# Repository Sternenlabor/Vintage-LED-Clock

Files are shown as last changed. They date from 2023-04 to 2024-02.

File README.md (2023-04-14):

# Vintage-LED-Clock
# WiFi configuration
SSID and credentials are kept in a separate file which is not included in GIT repository.   
Create file *credentials.h* in *src* folder and add SSID and WiFi password.   
e.g.:

    #ifndef _CREDENTIALS_H_
    #define _CREDENTIALS_H_

    const char cstrSSID[] = "MyNetwork";
    const char cstrPWD[] = "secret";

    #endif /* _CREDENTIALS_H_ */

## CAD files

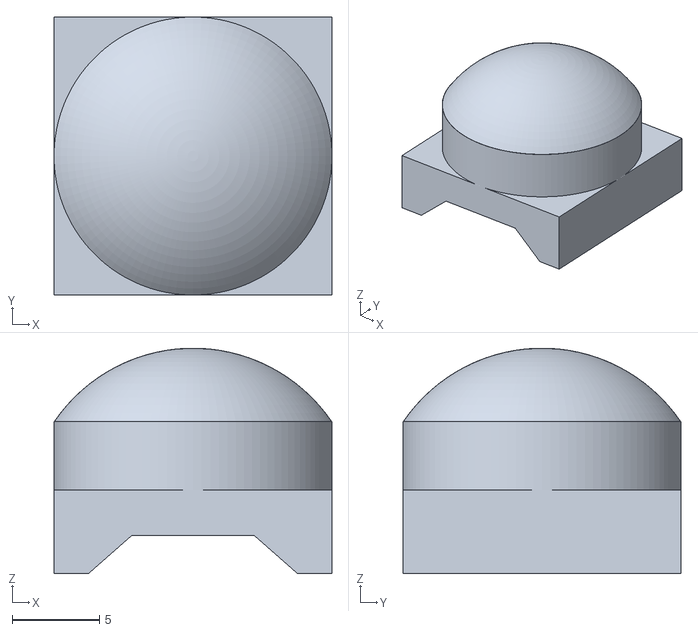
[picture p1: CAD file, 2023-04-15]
hardware/led-case/led-case.stl
15.9 x 15.9 x 12.9

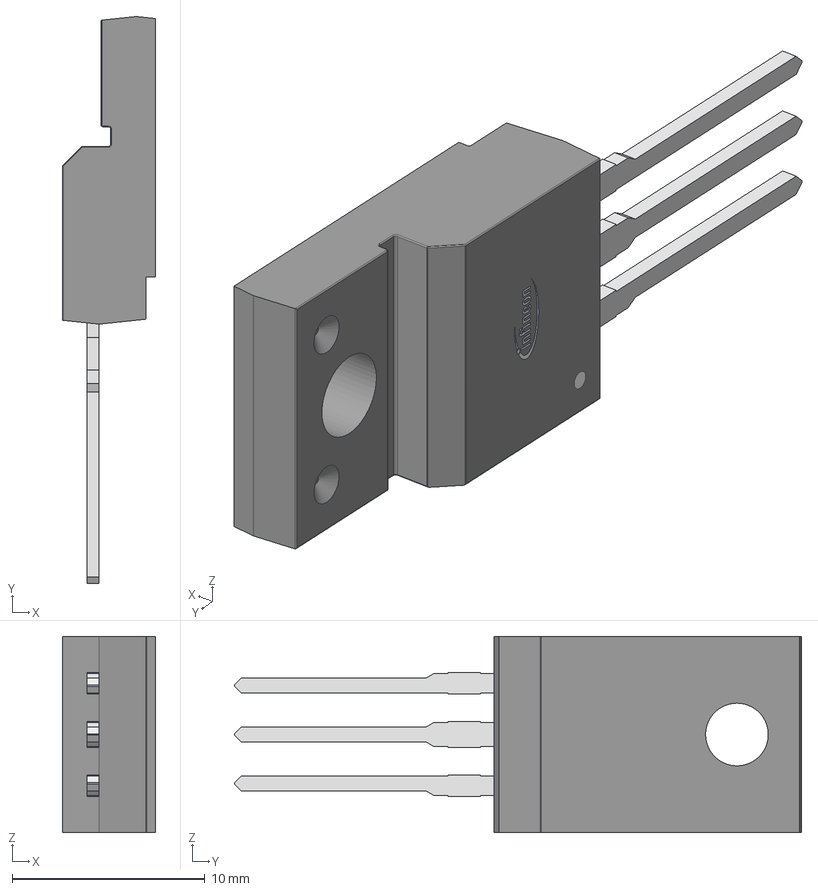
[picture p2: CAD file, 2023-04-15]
hardware/led-clock-mainboard/parts/IRF1404PBF.models/Infineon_Technologies_-_IRF1404PBF.step
4.83 x 29.4 x 10.2 mm
Infineon IRFB4127PbF 1
Infineon IRFB4127PbF 2
Infineon IRFB4127PbF 2_1
Infineon IRFB4127PbF 2 - Copy_MIR1
Infineon

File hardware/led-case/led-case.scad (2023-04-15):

$fn = 100;

width = 15.9; //mm
base_height = 4.8; //mm
ring_height = 3.9; //mm
overall_height = 12.9; //mm
wall_thickness = 0.9; //mm

cutout_height = 2.2; //mm
cutout_top_width = 5; //mm
cutout_bottom_width = 12; //mm

color("red") {
    difference() {
        
        // outer
        union() {
            translate([0, 0, base_height / 2]) cube([width, width, base_height], center=true);
            cylinder(base_height + ring_height, width / 2, width / 2);
            radius = (width / 2) + 1.65;
            difference() {
                translate([0, 0, overall_height - radius]) sphere(radius);
                translate([0, 0, -25 + base_height + ring_height]) cube([50, 50, 50], center=true); // mask
            }
        }
        
        // inner
        union() {
            w = wall_thickness;
            translate([0, 0, base_height / 2 - w - 0.01]) cube([width - 2 * w, width - 2 * w, base_height - 2 * w], center=true);
            cylinder((base_height + ring_height), (width - 2 * w) / 2, (width - 2 * w) / 2);
            
            radius = (width / 2) + 1;
            difference() {
                translate([0, 0, overall_height - radius - w + 0.05]) sphere(radius);
                translate([0, 0, -100 + base_height + ring_height - w + 0.8]) cube([200, 200, 200], center=true); // mask
            }
            
        }
        
        // cutout
        translate([-cutout_bottom_width / 2, width, -0.01]) rotate([90, 00, 0]) color("blue") linear_extrude(2 * width) polygon(points=[[0, 0], [cutout_bottom_width, 0],[cutout_bottom_width - cutout_top_width / 2, cutout_height], [cutout_top_width / 2, cutout_height]]);
        
        // Test
        //translate([0, 25, 0]) cube([50, 50, 50], center=true); // mask   
    }
}

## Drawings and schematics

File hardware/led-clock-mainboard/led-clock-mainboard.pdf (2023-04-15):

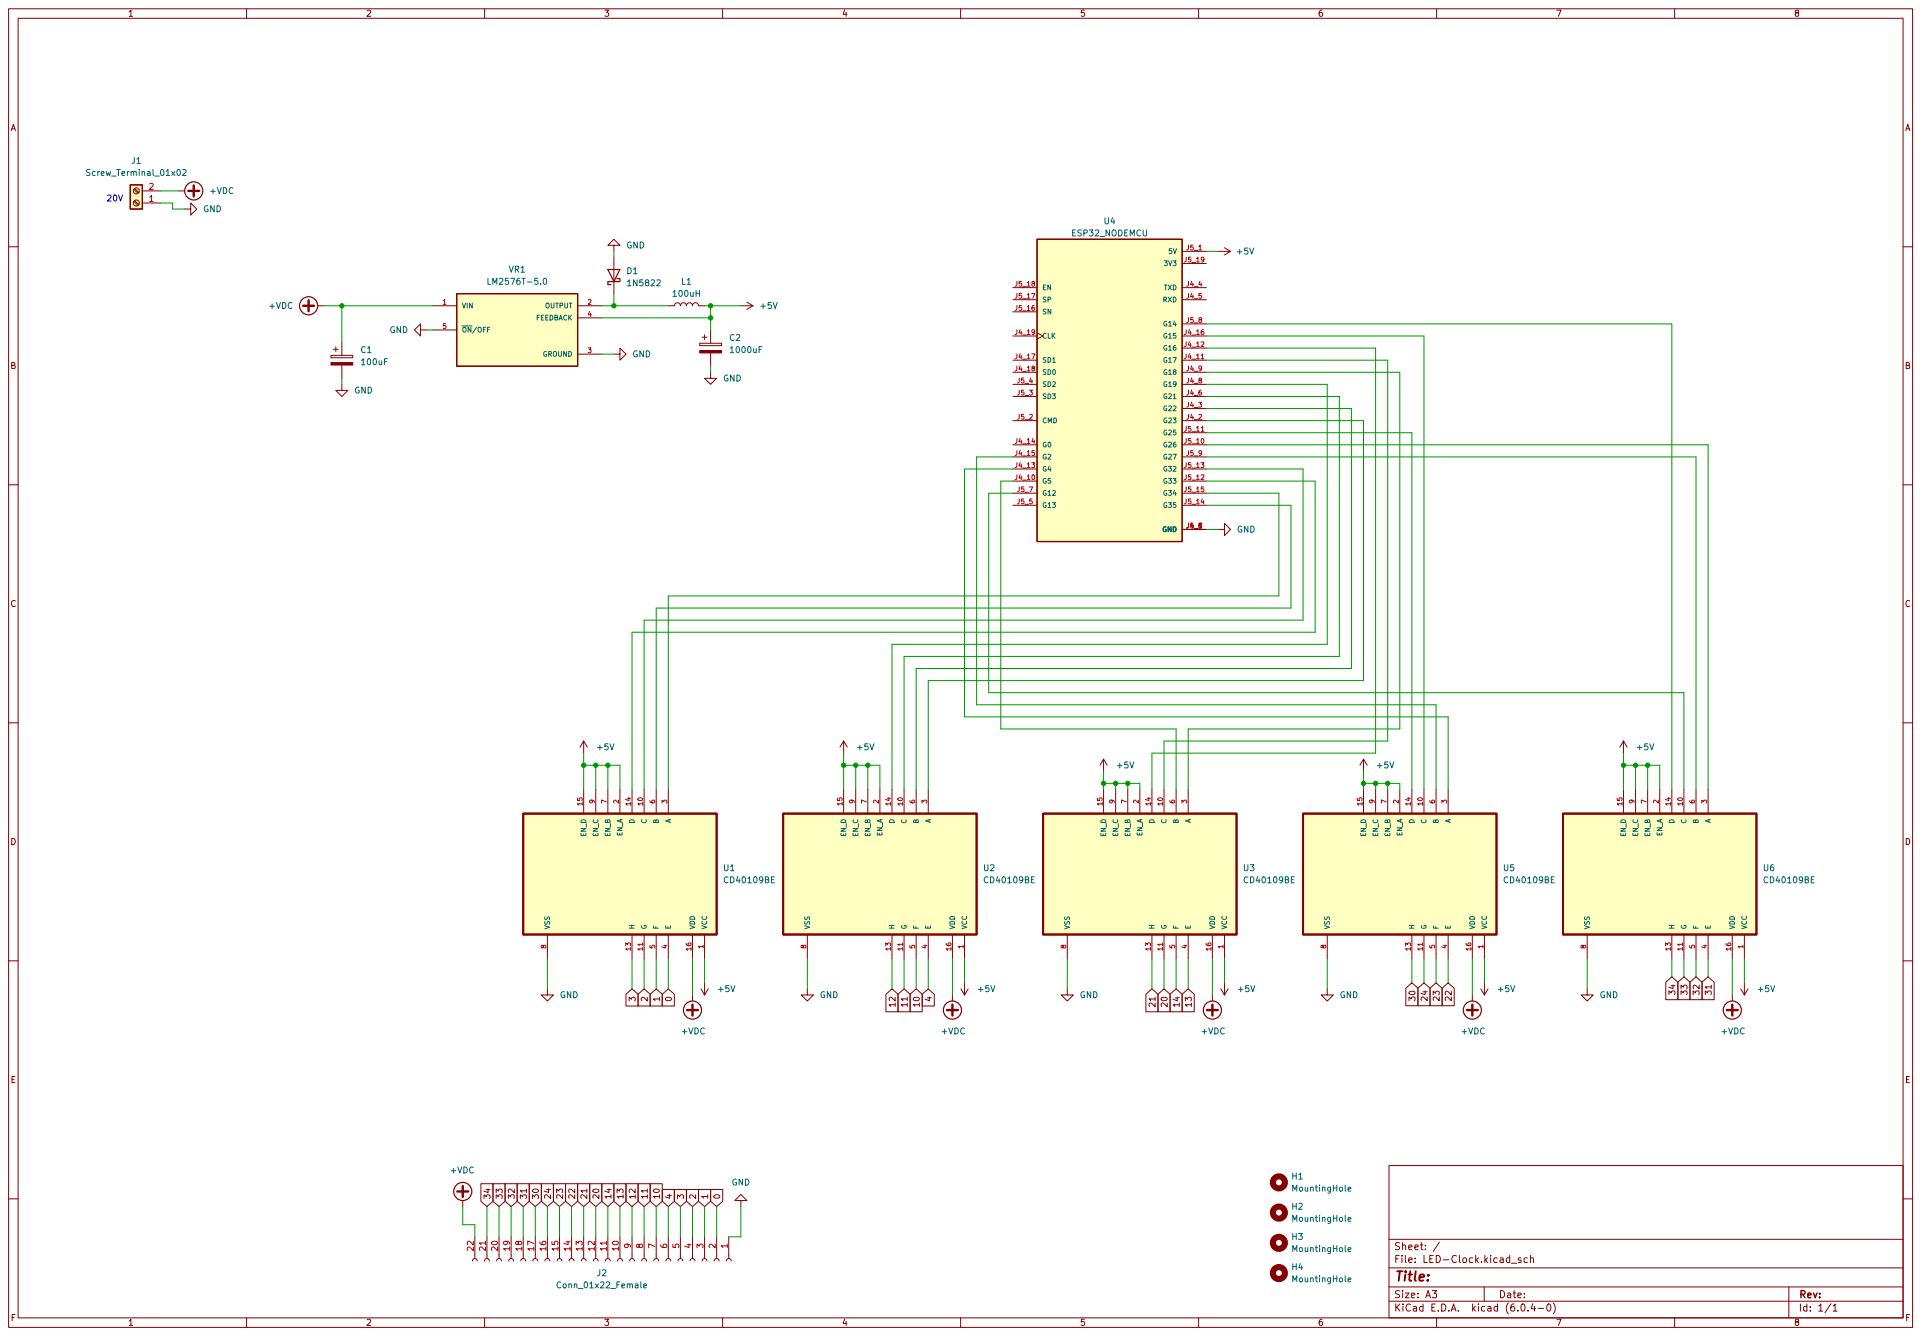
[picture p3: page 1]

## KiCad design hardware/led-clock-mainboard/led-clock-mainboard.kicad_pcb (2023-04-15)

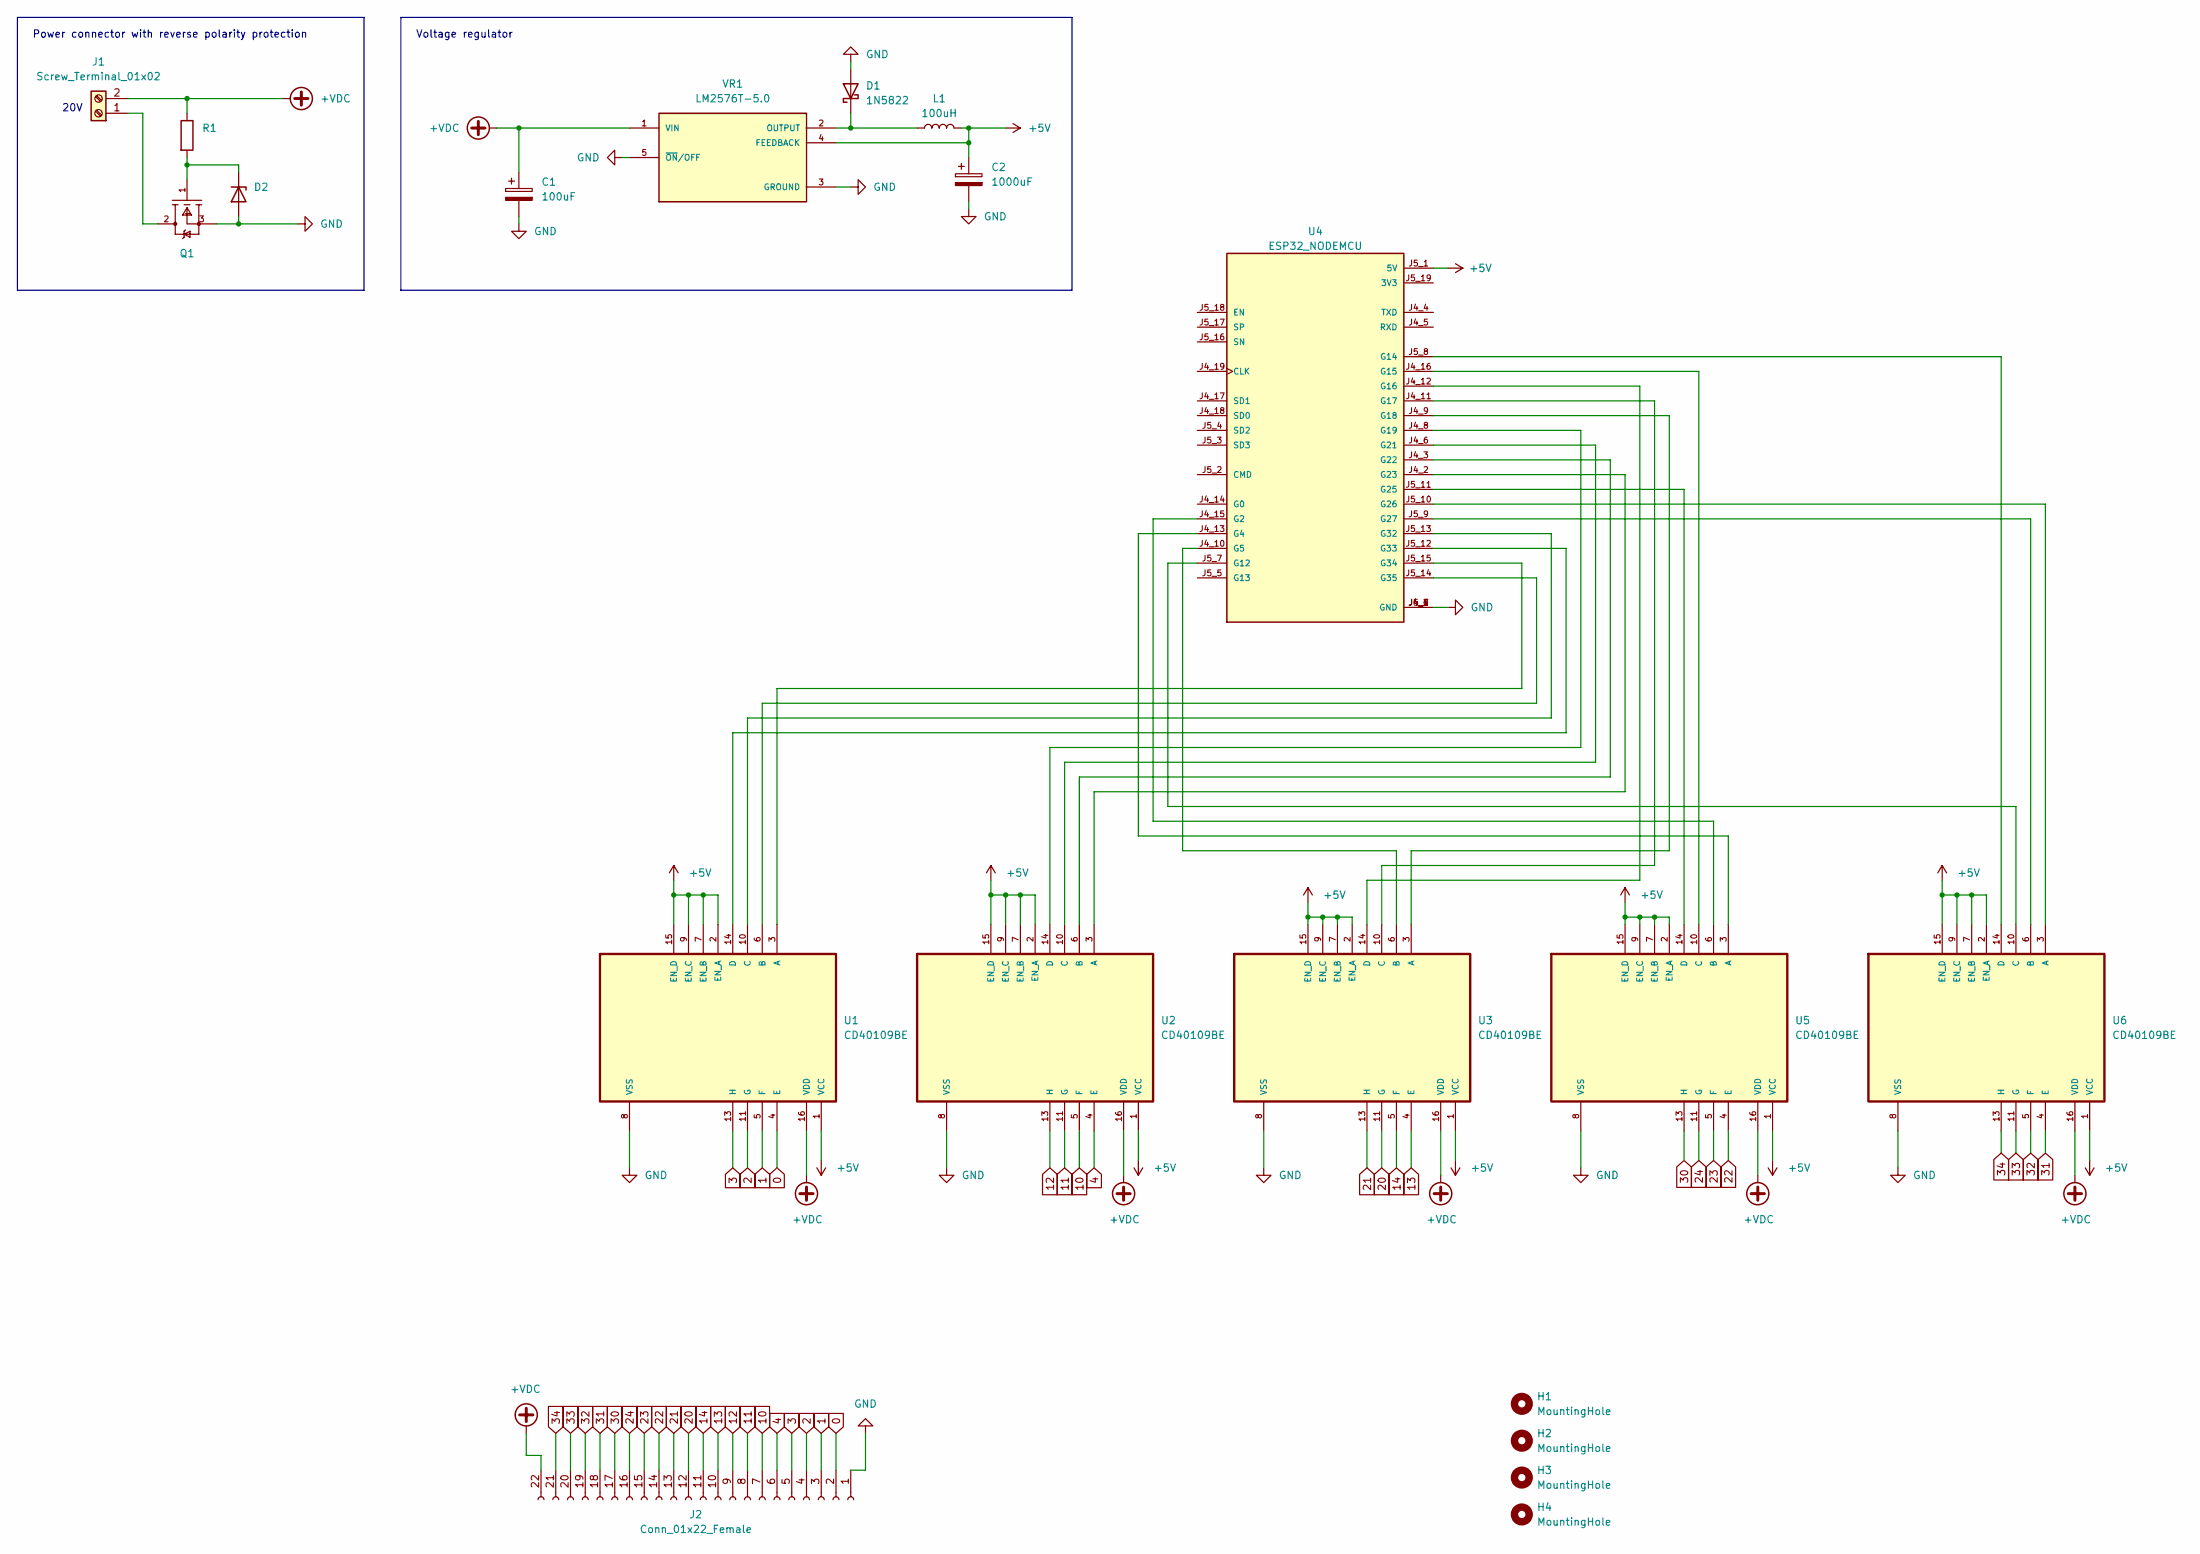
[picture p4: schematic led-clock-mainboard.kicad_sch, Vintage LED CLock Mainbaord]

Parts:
C1: 100uF; CP_Radial_D5.0mm_P2.50mm
C2: 1000uF; CP_Radial_D10.0mm_P5.00mm
D1: 1N5822; D_DO-201AD_P15.24mm_Horizontal
D2: (no value)
H1, H2, H3, H4: MountingHole; MountingHole_3.2mm_M3
J1: Screw_Terminal_01x02; TerminalBlock_Altech_AK300-2_P5.00mm
J2: Conn_01x22_Female; PinSocket_1x22_P2.54mm_Vertical
L1: 100uH; L_Radial_D9.5mm_P5.00mm_Fastron_07HVP
Q1: mouser part number 942-IRF1404PBF; digikey description MOSFET N-CH 40V 202A TO-220AB
R1: (no value)
U1, U2, U3, U5, U6: CD40109BE; DIP794W45P254L1969H508Q16
U4: ESP32_NODEMCU
VR1: LM2576T-5.0; TO170P1067X483X1651-5; PARTREV E

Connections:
0: J2.2, U1.4 (E)
1: J2.3, U1.5 (F)
2: J2.4, U1.11 (G)
3: J2.5, U1.13 (H)
4: J2.6, U2.4 (E)
10: J2.7, U2.5 (F)
11: J2.8, U2.11 (G)
12: J2.9, U2.13 (H)
13: J2.10, U3.4 (E)
14: J2.11, U3.5 (F)
20: J2.12, U3.11 (G)
21: J2.13, U3.13 (H)
22: J2.14, U5.4 (E)
23: J2.15, U5.5 (F)
24: J2.16, U5.11 (G)
30: J2.17, U5.13 (H)
31: J2.18, U6.4 (E)
32: J2.19, U6.5 (F)
33: J2.20, U6.11 (G)
34: J2.21, U6.13 (H)
+5V: C2.1, L1.2, U1.1 (VCC), U1.2 (EN_A), U1.7 (EN_B), U1.9 (EN_C), U1.15 (EN_D), U2.1 (VCC), U2.2 (EN_A), U2.7 (EN_B), U2.9 (EN_C), U2.15 (EN_D), U3.1 (VCC), U3.2 (EN_A), U3.7 (EN_B), U3.9 (EN_C), U3.15 (EN_D), U4.J5_1 (5V), U5.1 (VCC), U5.2 (EN_A), U5.7 (EN_B), U5.9 (EN_C), U5.15 (EN_D), U6.1 (VCC), U6.2 (EN_A), U6.7 (EN_B), U6.9 (EN_C), U6.15 (EN_D), VR1.4 (FEEDBACK)
+VDC: C1.1, J1.2, J2.22, R1.1, U1.16 (VDD), U2.16 (VDD), U3.16 (VDD), U5.16 (VDD), U6.16 (VDD), VR1.1 (VIN)
GND: C1.2, C2.2, D1.2 (A), D2.2 (A), J2.1, Q1.3 (SOURCE), U1.8 (VSS), U2.8 (VSS), U3.8 (VSS), U4.J4_1 (GND), U4.J4_7 (GND), U4.J5_6 (GND), U5.8 (VSS), U6.8 (VSS), VR1.3 (GROUND), VR1.5 (~ON/OFF)
unnamed: D1.1 (K), L1.1, VR1.2 (OUTPUT)
unnamed: D2.1 (K), Q1.1 (GATE), R1.2
unnamed: J1.1, Q1.2 (DRAIN)
unnamed: U1.3 (A), U4.J5_15 (G34)
unnamed: U1.6 (B), U4.J5_14 (G35)
unnamed: U1.10 (C), U4.J5_13 (G32)
unnamed: U1.14 (D), U4.J5_12 (G33)
unnamed: U2.3 (A), U4.J4_2 (G23)
unnamed: U2.6 (B), U4.J4_3 (G22)
unnamed: U2.10 (C), U4.J4_6 (G21)
unnamed: U2.14 (D), U4.J4_8 (G19)
unnamed: U3.3 (A), U4.J4_9 (G18)
unnamed: U3.6 (B), U4.J4_10 (G5)
unnamed: U3.10 (C), U4.J4_11 (G17)
unnamed: U3.14 (D), U4.J4_12 (G16)
unnamed: U4.J4_13 (G4), U5.3 (A)
unnamed: U4.J4_15 (G2), U5.6 (B)
unnamed: U4.J4_16 (G15), U5.10 (C)
unnamed: U4.J5_7 (G12), U6.10 (C)
unnamed: U4.J5_8 (G14), U6.14 (D)
unnamed: U4.J5_9 (G27), U6.6 (B)
unnamed: U4.J5_10 (G26), U6.3 (A)
unnamed: U4.J5_11 (G25), U5.14 (D)

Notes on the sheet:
20V
Power connector with reverse polarity protection
Voltage regulator

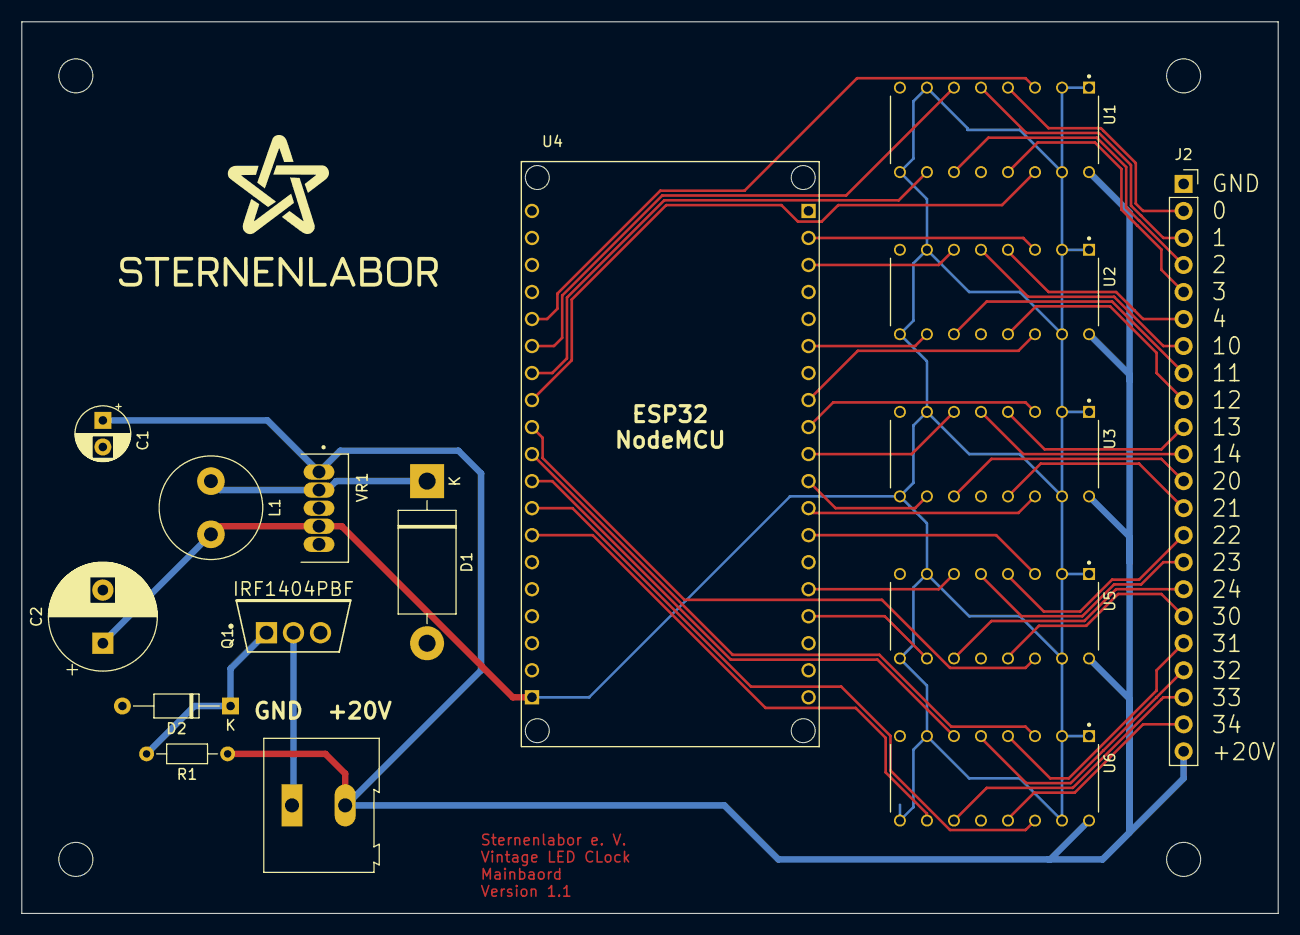
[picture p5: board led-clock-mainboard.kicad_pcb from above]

Board: 2 copper layers, 118.1 x 83.8 mm, 20 parts (0 on the bottom side), 46 nets.

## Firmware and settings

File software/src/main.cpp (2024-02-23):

#include <Arduino.h>
#include <WiFi.h>


#include "tsk_timupdate.h"
#include "tsk_clock.h"
#include "tsk_udp.h"



void setup()
{
   Serial.begin(115200);
   Serial.setDebugOutput(true);
   
   Serial.println("Initializing Tasker.");
   Tasker* pTasker = Tasker::GetInstance();
   pTasker->AddTask(new TskTimeUpdate(false));
   pTasker->AddTask(new TskClock());
   pTasker->AddTask(new TskUdp());
    
   Serial.println("setup() completed");
   

}

void loop()
{
   Tasker::GetInstance()->Run();
   // g_LedClock.digitalClockDisplay();
   // delay(1000);
}

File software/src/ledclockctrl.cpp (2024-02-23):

#include "ledclockctrl.h"
#include "time.h"

enum PWM_LED_CHANNELS
{
   PWM_LED_CHANNEL_OFF,
   PWM_LED_CHANNEL_1,
   PWM_LED_CHANNEL_2,
   PWM_LED_CHANNEL_3,
   PWM_LED_CHANNEL_4
};

#define PWM_LED_FREQUENCY 1000 //!< frequency in Hz
#define PWM_LED_RESOLUTION 8   //!< PWM resolution in bits

stcPin g_stcPinConfHourHigh[CHARS_PER_DIGIT][NUM_OUTPUTS_PER_DIGIT] = {
    {{13, LOW},
     {0, LOW},
     {32, LOW},
     {33, LOW},
     {23, HIGH}},
    {{13, HIGH},
     {0, LOW},
     {32, LOW},
     {33, LOW},
     {23, HIGH}},
    {{13, LOW},
     {0, HIGH},
     {32, LOW},
     {33, LOW},
     {23, HIGH}},
    {{13, HIGH},
     {0, HIGH},
     {32, LOW},
     {33, LOW},
     {23, HIGH}},
    {{13, LOW},
     {0, LOW},
     {32, HIGH},
     {33, LOW},
     {23, HIGH}},
    {{13, HIGH},
     {0, LOW},
     {32, HIGH},
     {33, LOW},
     {23, HIGH}},
    {{13, LOW},
     {0, HIGH},
     {32, HIGH},
     {33, LOW},
     {23, HIGH}},
    {{13, HIGH},
     {0, HIGH},
     {32, HIGH},
     {33, LOW},
     {23, HIGH}},
    {{13, LOW},
     {0, LOW},
     {32, LOW},
     {33, HIGH},
     {23, HIGH}},
    {{13, HIGH},
     {0, LOW},
     {32, LOW},
     {33, HIGH},
     {23, HIGH}},
    {{13, LOW}, // 11 all off
     {0, LOW},
     {32, LOW},
     {33, LOW},
     {23, LOW}}};

stcPin g_stcPinConfHourLow[CHARS_PER_DIGIT][NUM_OUTPUTS_PER_DIGIT] = {
    {{22, LOW},
     {21, LOW},
     {19, LOW},
     {18, LOW},
     {5, HIGH}},
    {{22, HIGH},
     {21, LOW},
     {19, LOW},
     {18, LOW},
     {5, HIGH}},
    {{22, LOW},
     {21, HIGH},
     {19, LOW},
     {18, LOW},
     {5, HIGH}},
    {{22, HIGH},
     {21, HIGH},
     {19, LOW},
     {18, LOW},
     {5, HIGH}},
    {{22, LOW},
     {21, LOW},
     {19, HIGH},
     {18, LOW},
     {5, HIGH}},
    {{22, HIGH},
     {21, LOW},
     {19, HIGH},
     {18, LOW},
     {5, HIGH}},
    {{22, LOW},
     {21, HIGH},
     {19, HIGH},
     {18, LOW},
     {5, HIGH}},
    {{22, HIGH},
     {21, HIGH},
     {19, HIGH},
     {18, LOW},
     {5, HIGH}},
    {{22, LOW},
     {21, LOW},
     {19, LOW},
     {18, HIGH},
     {5, HIGH}},
    {{22, HIGH},
     {21, LOW},
     {19, LOW},
     {18, HIGH},
     {5, HIGH}},
    {{22, LOW}, // 11 all off
     {21, LOW},
     {19, LOW},
     {18, LOW},
     {5, LOW}}};

stcPin g_stcPinConfMinHigh[CHARS_PER_DIGIT][NUM_OUTPUTS_PER_DIGIT] = {
    {{17, LOW},
     {16, LOW},
     {4, LOW},
     {2, LOW},
     {15, HIGH}},
    {{17, HIGH},
     {16, LOW},
     {4, LOW},
     {2, LOW},
     {15, HIGH}},
    {{17, LOW},
     {16, HIGH},
     {4, LOW},
     {2, LOW},
     {15, HIGH}},
    {{17, HIGH},
     {16, HIGH},
     {4, LOW},
     {2, LOW},
     {15, HIGH}},
    {{17, LOW},
     {16, LOW},
     {4, HIGH},
     {2, LOW},
     {15, HIGH}},
    {{17, HIGH},
     {16, LOW},
     {4, HIGH},
     {2, LOW},
     {15, HIGH}},
    {{17, LOW},
     {16, HIGH},
     {4, HIGH},
     {2, LOW},
     {15, HIGH}},
    {{17, HIGH},
     {16, HIGH},
     {4, HIGH},
     {2, LOW},
     {15, HIGH}},
    {{17, LOW},
     {16, LOW},
     {4, LOW},
     {2, HIGH},
     {15, HIGH}},
    {{17, HIGH},
     {16, LOW},
     {4, LOW},
     {2, HIGH},
     {15, HIGH}},
    {{17, LOW}, // 11 all off
     {16, LOW},
     {4, LOW},
     {2, LOW},
     {15, LOW}}};

stcPin g_stcPinConfMinLow[CHARS_PER_DIGIT][NUM_OUTPUTS_PER_DIGIT] = {
    {{25, LOW},
     {26, LOW},
     {27, LOW},
     {12, LOW},
     {14, HIGH}},
    {{25, HIGH},
     {26, LOW},
     {27, LOW},
     {12, LOW},
     {14, HIGH}},
    {{25, LOW},
     {26, HIGH},
     {27, LOW},
     {12, LOW},
     {14, HIGH}},
    {{25, HIGH},
     {26, HIGH},
     {27, LOW},
     {12, LOW},
     {14, HIGH}},
    {{25, LOW},
     {26, LOW},
     {27, HIGH},
     {12, LOW},
     {14, HIGH}},
    {{25, HIGH},
     {26, LOW},
     {27, HIGH},
     {12, LOW},
     {14, HIGH}},
    {{25, LOW},
     {26, HIGH},
     {27, HIGH},
     {12, LOW},
     {14, HIGH}},
    {{25, HIGH},
     {26, HIGH},
     {27, HIGH},
     {12, LOW},
     {14, HIGH}},
    {{25, LOW},
     {26, LOW},
     {27, LOW},
     {12, HIGH},
     {14, HIGH}},
    {{25, HIGH},
     {26, LOW},
     {27, LOW},
     {12, HIGH},
     {14, HIGH}},
    {{25, LOW}, // 11 all off
     {26, LOW},
     {27, LOW},
     {12, LOW},
     {14, LOW}}};

LedClockControl::LedClockControl(bool bEnableDimming, uint8_t uiBrigthnessPercent) : m_bEnableDimming(bEnableDimming)
{
   // fill in default data
   for (uint8_t i = DIG_FIRST; i < DIG_LAST; i++)
   {
      m_stcDigitData[i].uiDigit = i;
      m_stcDigitData[i].uiPwmChannel = i + PWM_LED_CHANNEL_1;
      m_stcDigitData[i].uiBrightness = (255 / 100.0) * uiBrigthnessPercent;
   }

   // set pin data
   m_stcDigitData[DIG_HOUR_HIGH].pPinData = &g_stcPinConfHourHigh;
   m_stcDigitData[DIG_HOUR_LOW].pPinData = &g_stcPinConfHourLow;
   m_stcDigitData[DIG_MINUTE_HIGH].pPinData = &g_stcPinConfMinHigh;
   m_stcDigitData[DIG_MINUTE_LOW].pPinData = &g_stcPinConfMinLow;
}

LedClockControl::~LedClockControl()
{
   // nothing to do
}

void LedClockControl::begin()
{
   if (!m_bEnableDimming)
   {
      // no dimming init GPIOs as normal outputs
      for (uint8_t j = DIG_FIRST; j < DIG_LAST; j++)
      {
         for (uint8_t i = 0; i < NUM_OUTPUTS_PER_DIGIT; i++)
         {
            charMapping_t *pTmp = m_stcDigitData[j].pPinData;
            pinMode((*pTmp)[0][i].pin_number, OUTPUT);
         }
      }
   }
   else
   {
      ledcSetup(PWM_LED_CHANNEL_OFF, PWM_LED_FREQUENCY, PWM_LED_RESOLUTION);
      ledcWrite(PWM_LED_CHANNEL_OFF, 0);

      for (uint8_t j = DIG_FIRST; j < DIG_LAST; j++)
      {
         ledcSetup(m_stcDigitData[j].uiPwmChannel, PWM_LED_FREQUENCY, PWM_LED_RESOLUTION);
         ledcWrite(m_stcDigitData[j].uiPwmChannel, m_stcDigitData[j].uiBrightness);
      };
   }

   updateDigits(SEGMENT_OFF, SEGMENT_OFF, SEGMENT_OFF, SEGMENT_OFF);
}

void LedClockControl::digitalClockDisplay()
{
   struct tm timeinfo;
   if (!getLocalTime(&timeinfo))
   {
      Serial.println("Failed to obtain time");
      return;
   }

   char h[3];
   strftime(h, 3, "%H", &timeinfo);

   char m[3];
   strftime(m, 3, "%M", &timeinfo);

   int hours = String(h).toInt();
   int minutes = String(m).toInt();

   int temp = hours;   // Get the hours and save to variable temp
   int h1 = temp / 10; // Split hours into two digits, tens and units
   int h2 = temp % 10;
   temp = minutes;     // Get the minutes and save to variable temp
   int m1 = temp / 10; // Split minutes into two digits, tens and units
   int m2 = temp % 10;

   //Serial.println(String(h1) + "-" + String(h2) + ":" + String(m1) + "-" + String(m2));
   updateDigits(h1, h2, m1, m2);
}
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

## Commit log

2022-09-15 do not track
2023-04-11 Use separate PWM for each digit (never work :) )
2023-04-15 Fixed a PCB layout issue (missing track) and added reverse power protection
    [Infineon_Technologies_-_IRF1404PBF.step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]
2023-04-15 added LED case design
    [led-case.scad, led-case.stl]
2023-04-15 small modification for LED case
    [led-case.scad, led-case.stl]
